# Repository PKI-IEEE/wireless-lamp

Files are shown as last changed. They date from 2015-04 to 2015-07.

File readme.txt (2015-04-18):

This is an LPCXpresso project for the LPC1343 that is being used on an RGBW Lamp for a PKI IEEE project Spring 2015. The lamp also uses an ESP8266 Wifi module.

Function Descriptions:

void setRed(uint8_t setValue);
Sets the red LED. Takes uint8_t value from 0 to 255 which controls the
brightness of the LED.
Example use:
	setRed(128) // sets red led to medium brightness

void setGreen(uint8_t setValue);
Sets the green LED. Takes uint8_t value from 0 to 255 which controls the
brightness of the LED.
Example use:
	setGreen(128) // sets green led to medium brightness

void setBlue(uint8_t setValue);
Sets the blue LED. Takes uint8_t value from 0 to 255 which controls the
brightness of the LED.
Example use:
	setBlue(128) // sets blue led to medium brightness

void setWhite(uint8_t setValue);
Sets the white LED. Takes uint8_t value from 0 to 255 which controls the
brightness of the LED.
Example use:
	setWhite(128) // sets white led to medium brightness

void setColor(uint8_t red, uint8_t green, uint8_t blue, uint8_t white);
Sets all 4 LEDs at once. Can be used to blend the LED colors.
Takes four uint8_t value from 0 to 255 which control the
brightness of the LEDs.
Example use:
	setColor(255, 255, 0, 0); // sets lamp to produce yellow color at full brightness

void testRed();
Brings the red led from off to full brightness in about 13 seconds.
	Example use:
		testRed();

void testGreen();
Brings the green led from off to full brightness in about 13 seconds.
	Example use:
		testGreen();

void testBlue();
Brings the blue led from off to full brightness in about 13 seconds.
	Example use:
		testBlue();

void testWhite();
Brings the white led from off to full brightness in about 13 seconds.
	Example use:
		testWhite();

void delay_us(uint32_t delay);
Uses TMR16B0 to create a delay in us.
	Example use:
		delay_us(1000); // delays for 1000 us

void delay_ms(uint32_t delay);
Uses delay_us function in a loop to create delay in ms
	Example use:
		delay_ms(1000); // delays for 1 second

void colorWheel(uint32_t delay);
Function written by Austin Steiner. Cycles gradually through the colors much like a color wheel.
Takes a uint32_t value that specifies the delay between changing colors in ms (100 is a good starting value)
Each call the the function cycles through the colors once. Best used in a loop.
	Example use:
		colorWheel(100);

void wifiConnect();
Sends UART command to EPS8266 running nodeMCU firmware to connect to a WiFi network.
Before calling this function ensure that you update the staConfig string in the function
to include your SSID and password.
	Example use:
		wifiConnect(); // causes ESP8266 to connect to Wifi network in station mode

struct ipStc getIp();
Returns a structure containing the four integer parts of the ESP8266s current IP address

void blinkIp(struct ipStc ipAddress);
This function takes an ipStc structure containing the current ESP8266s IP address and then
blinks the LEDs in a manner that will let the user know this IP address:

Blink Red = 100
Blink Blue = 10
Blink Green = 1
Blink white = dot (.)
Blink purple = end of IP

Example blink pattern:

Blue - White - Green Green Green - White - Red Blue Green Green - White - Blue Blue Green - Purple

This IP would be : 10.3.(100+10+2).(10+10+1) = 10.3.112.21

Example Use:
	blinkIp(getIp()); // blinks the LEDs to show the IP address using structure returned by getIp() function

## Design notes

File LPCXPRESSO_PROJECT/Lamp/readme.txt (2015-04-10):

This project contains the code for the RGBW LED Lamp. IEEE Spring 2015

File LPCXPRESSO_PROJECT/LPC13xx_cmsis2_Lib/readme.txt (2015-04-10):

LPC13xx_cmsis2_Lib
==================

This library project contains code to handle various peripherals contained
in the LPC13xx.

Several files have been modified slightly from the original NXP sources to
comment out application specific code (mainly the interrupt handlers).

This means that the library project only contains the common code. Interrupt
handlers are moved into projects making use of the peripherals.

The project makes use of code from the following library project:
- CMSISv2p00_LPC13xx : for CMSIS 2.00 files relevant to LPC13xx

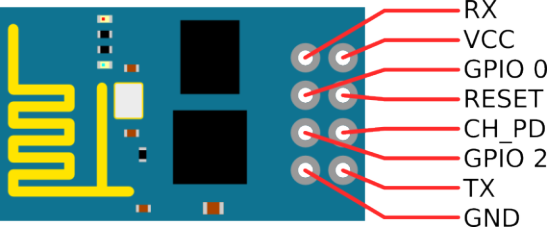
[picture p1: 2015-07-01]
BUILD_RELATED/esp8266_pinout.png

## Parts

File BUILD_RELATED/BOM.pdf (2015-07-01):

Component | Part Number | Quantity
Microcontroller | 568-4945-ND | 1
100k resistor | P100KFCT-ND | 5
150 resistor | P150ECT-ND | 2
1.5k resistor | P1.50KFCT-ND | 1
20k resistor | P20.0KFCT-ND | 1
10k resistor | P10.0KFCT-ND | 2
2k resistor | P2.00KFCT-ND | 1
1k resistor | P1.00KFCT-ND | 1
33 resistor | P33.0FCT-ND | 2
15 1W resistor | 15DLCT-ND | 2
10 1W resistor | 10WCT-ND | 6
10uF capacitor | 1276-1075-1-ND | 5
0.1uf capacitor | 1276-1017-1-ND | 5
16pF capacitor | 1276-2809-1-ND | 2
220uF capacitor | 493-5904-1-ND | 4
12MHz crystal | 644-1047-1-ND | 1
Tact Switch | P12940SCT-ND | 2
USB Mini B | ED2992CT-ND | 1
LED (USB, PWR Indicator) | 754-1141-1-ND | 2
Schottiky Diode Array | 497-3786-1-ND | 1
3.3V Regulator | LM1117IMPX-3.3/NOPBCT-ND | 1
PNP Transistor | MMBT2907A-TPMSCT-ND | 1
IC Supervisor 3.15V | MCP130T-315I/TTCT-ND | 1
PCB | | 1
N-Channel MOSFET | FQP50N06L-ND | 4
1W Power LED | 4W RGBW | 2
Wifi Module | ESP8266 | 1
Female Headers 4 pin | | 2
Female Headers 40 pin | | 1
Barrel Jack | EJ508A-ND | 1
DC Supply | 2.5A | 1

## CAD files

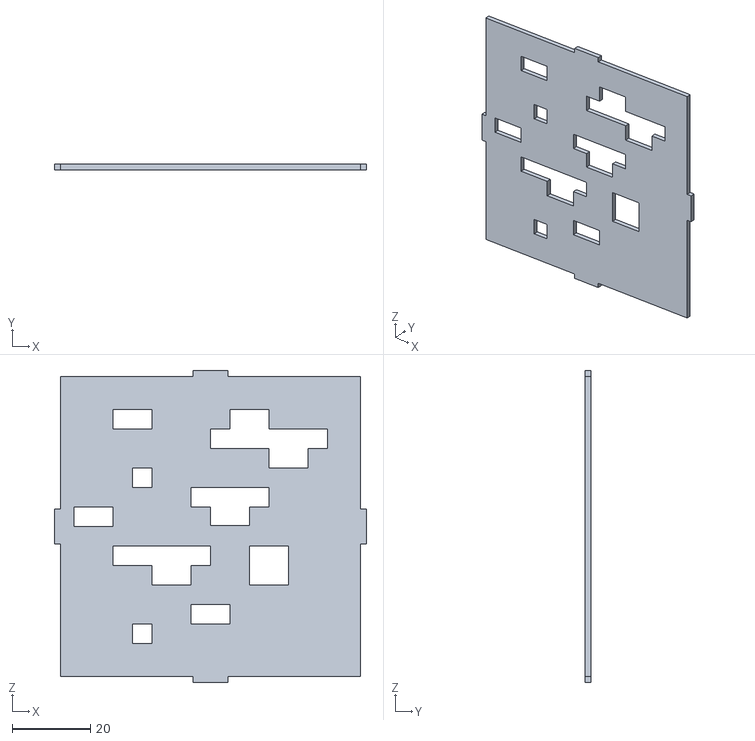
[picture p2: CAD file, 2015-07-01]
BUILD_RELATED/STLs/minecraft_wall_2.stl
80.0 x 1.50 x 80.0

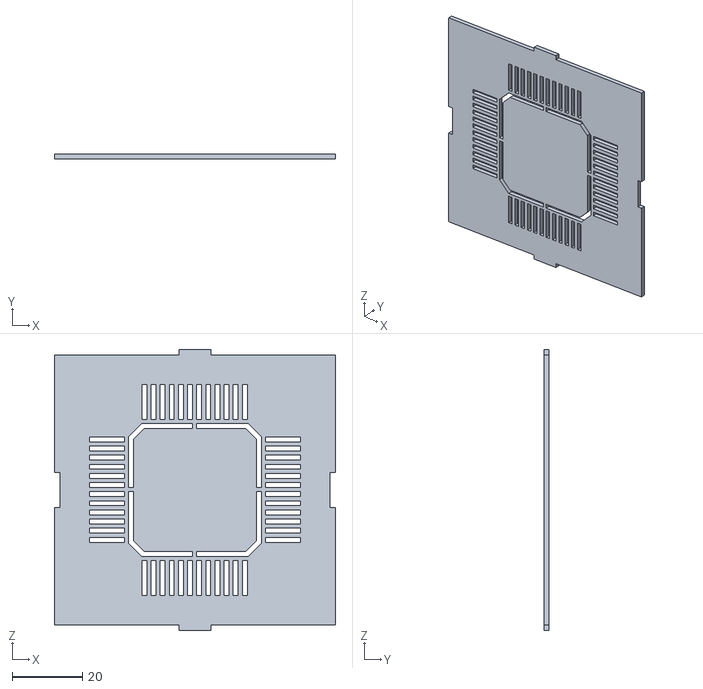
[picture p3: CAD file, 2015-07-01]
BUILD_RELATED/STLs/circuit_wall_2.stl
80.0 x 1.50 x 80.0

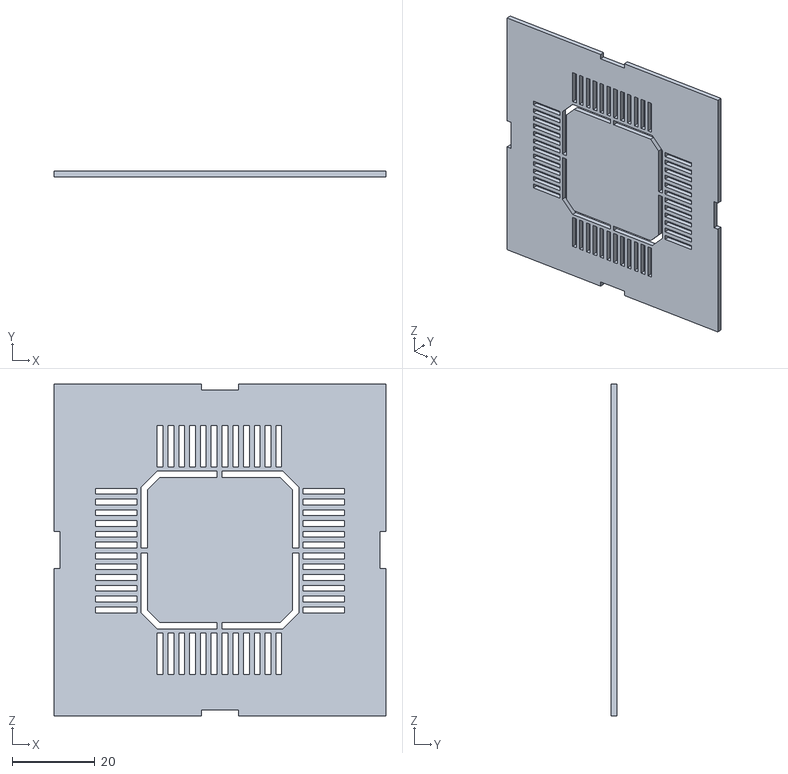
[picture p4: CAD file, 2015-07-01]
BUILD_RELATED/STLs/circuit_top.stl
80.0 x 1.50 x 80.0

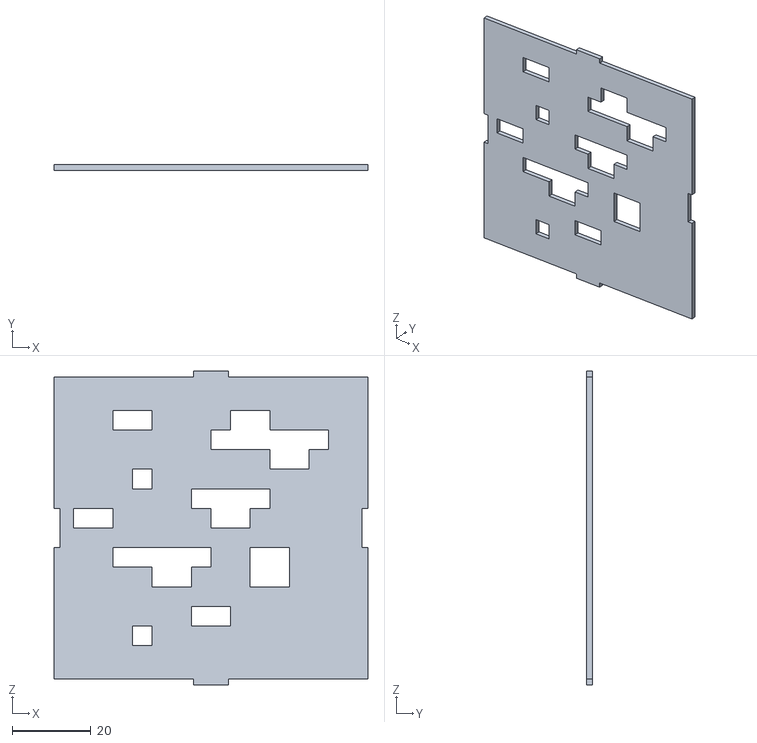
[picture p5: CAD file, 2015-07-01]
BUILD_RELATED/STLs/minecraft_wall_1.stl
80.0 x 1.50 x 80.0

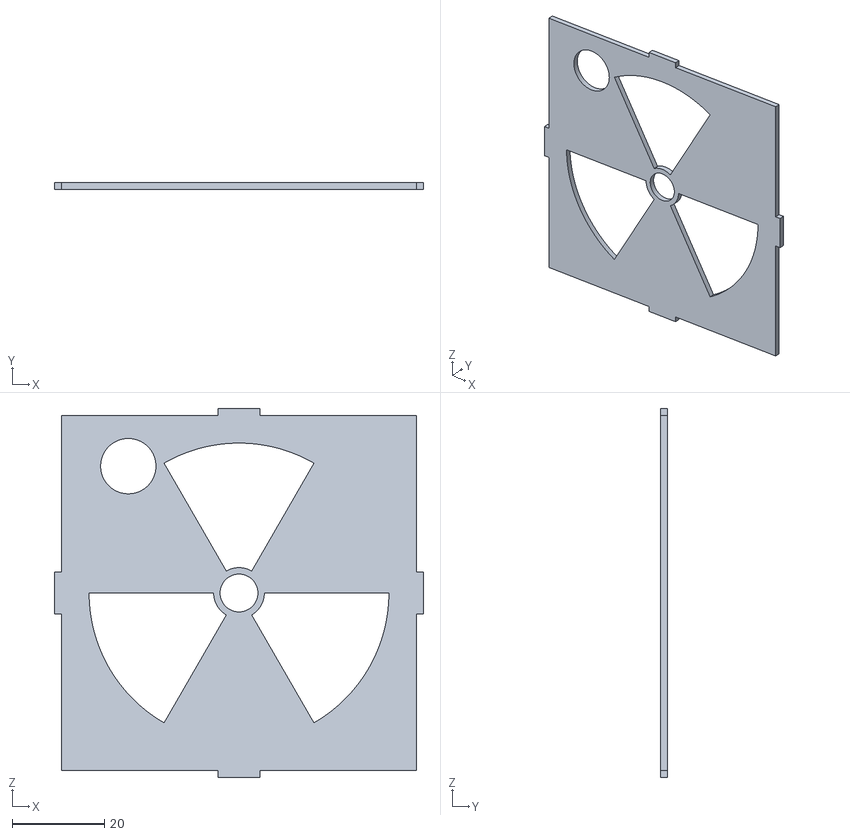
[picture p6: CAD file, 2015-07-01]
BUILD_RELATED/STLs/hazard_wall_3.stl
80.0 x 1.50 x 80.0

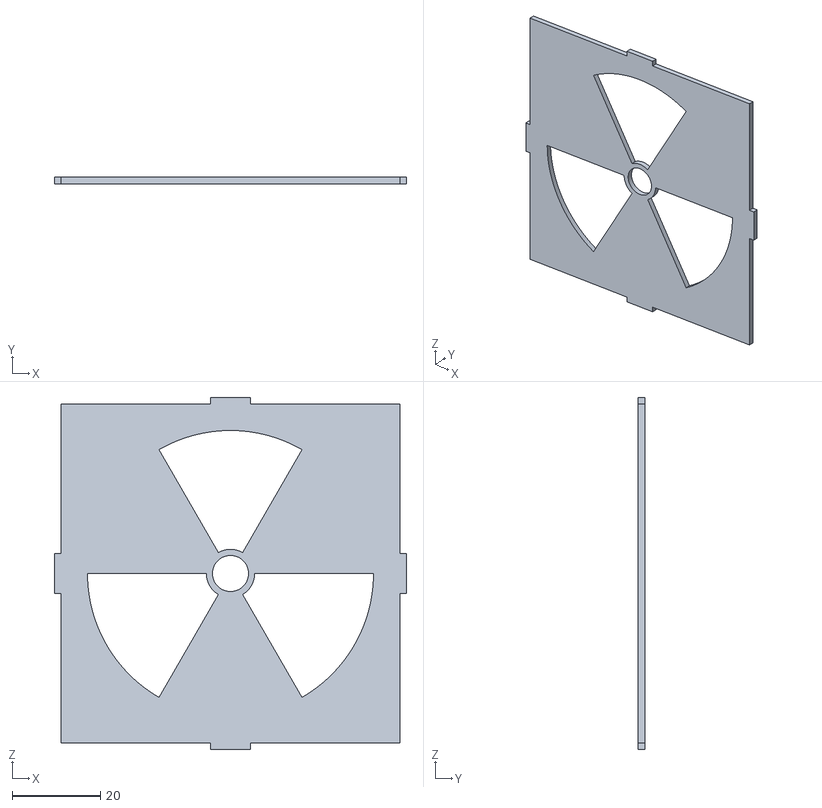
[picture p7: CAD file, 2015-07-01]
BUILD_RELATED/STLs/hazard_wall_1.stl
80.0 x 1.50 x 80.0

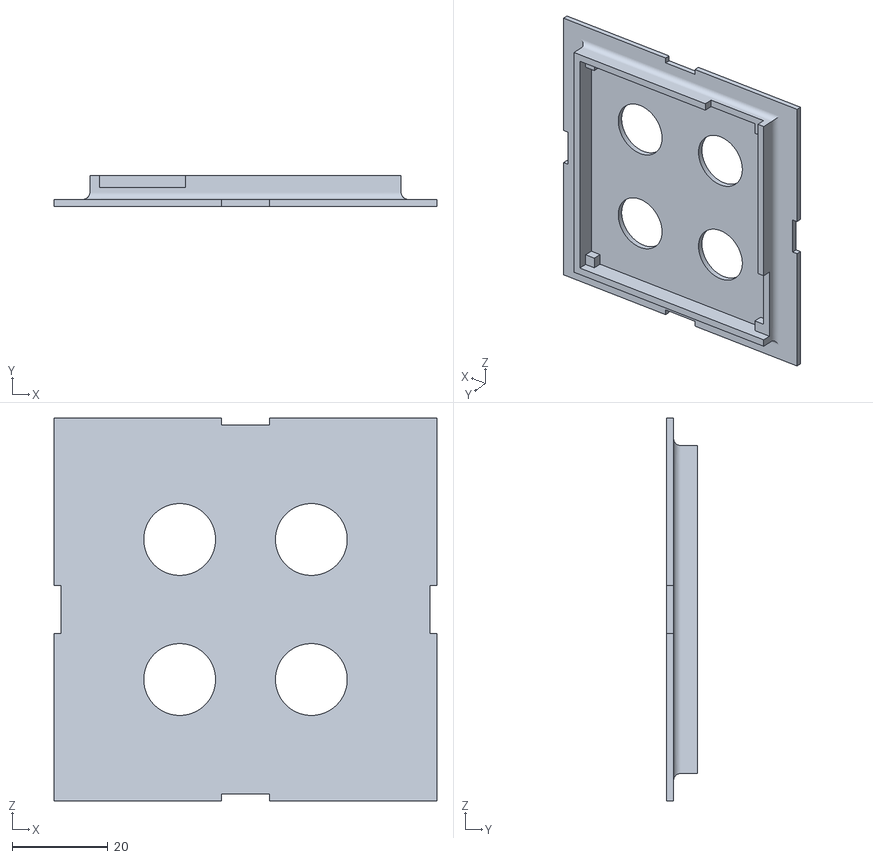
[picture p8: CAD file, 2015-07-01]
BUILD_RELATED/STLs/lamp_bottom.stl
80.0 x 6.50 x 80.0

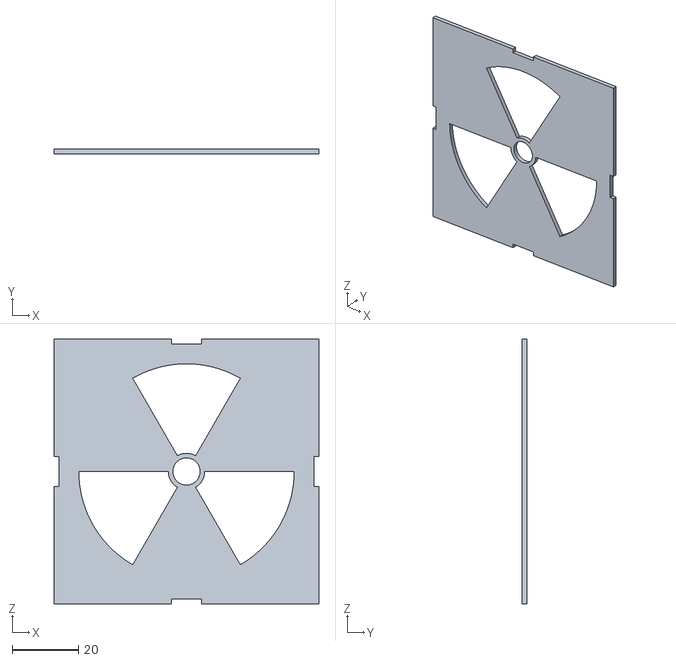
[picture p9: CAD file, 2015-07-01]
BUILD_RELATED/STLs/hazard_top.stl
80.0 x 1.50 x 80.0

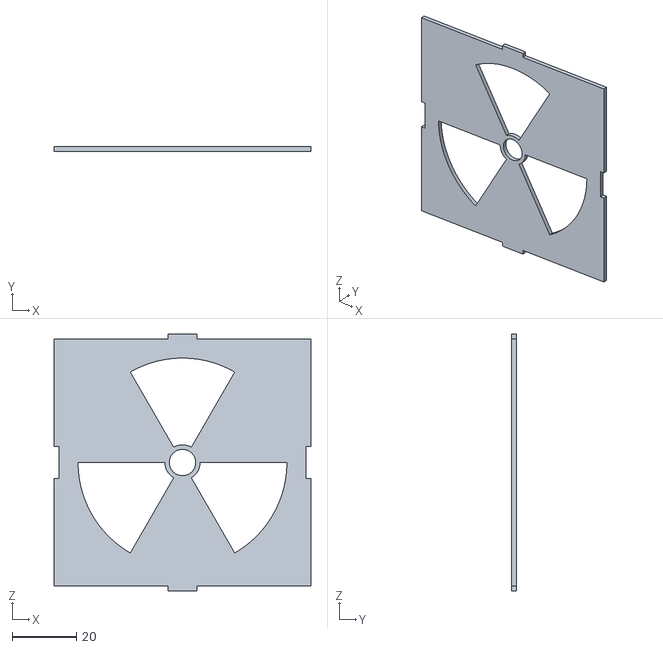
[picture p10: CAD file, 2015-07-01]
BUILD_RELATED/STLs/hazard_wall_2.stl
80.0 x 1.50 x 80.0

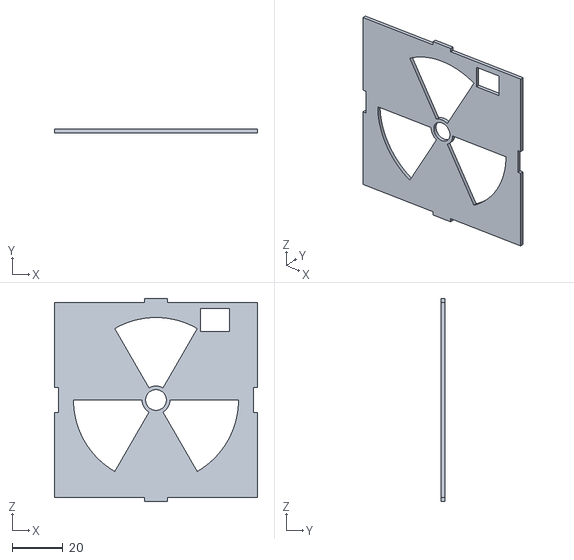
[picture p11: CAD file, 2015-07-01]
BUILD_RELATED/STLs/hazard_wall_4.stl
80.0 x 1.50 x 80.0

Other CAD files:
BUILD_RELATED/STLs/circuit_wall_1.stl
BUILD_RELATED/STLs/minecraft_wall_4.stl
BUILD_RELATED/STLs/circuit_wall_3.stl
BUILD_RELATED/STLs/minecraft_top.stl
BUILD_RELATED/STLs/minecraft_wall_3.stl
BUILD_RELATED/STLs/circuit_wall_4.stl

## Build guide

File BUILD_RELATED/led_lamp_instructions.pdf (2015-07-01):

# LED Wi-Fi Lamp Build Instructions

# PKI IEEE April 2015

Component | Quantity
Microcontroller | 1
100k Ω resistor | 5
150 Ω resistor | 2
1.5k Ω resistor | 1
20k Ω resistor | 1
10k Ω resistor | 2
2k Ω resistor | 1
1k Ω resistor | 1
33 Ω resistor | 2
15 Ω 1W resistor | 2
10 Ω 1W resistor | 6
10uF capacitor | 5
0.1uf capacitor | 5
16pF capacitor | 2
220uF capacitor | 4
12MHz crystal | 1
Tact Switch | 2
USB Mini B | 1
LED (USB, PWR Indicator) | 2
Schottky Diode Array | 1
3.3V Regulator | 1
PNP Transistor | 1
IC Supervisor 3.15V | 1
PCB | 1
N -Channel MOSFET | 4
1W RGBW LED | 2
ESP8266 Wi -Fi Module | 1
Female Headers 4 pin | 2
Female Headers 40 pin | 1
Barrel Jack | 1
DC Supply | 1

This project will be more involved and will require a greater attention to detail than some of the previous projects. Please take your time when assembling this project. If you have any questions, if anything is unclear, or if you need assistance, please ask.

When soldering surface mount devices (SMD) only remove one component from the tape at a time. These parts are small and can be easily lost. There are not many extra parts so if you do loose one you will have to search for it.

There is not a special order the components of this PCB should be soldered in. It is
recommended that you choose one component and solder all of those components at one time. For instance, there are five 10µF capacitors. All five should be soldered before moving on. This will reduce the likelihood of loosing a component.

You may want to look through all of the pages of these instructions before you begin.

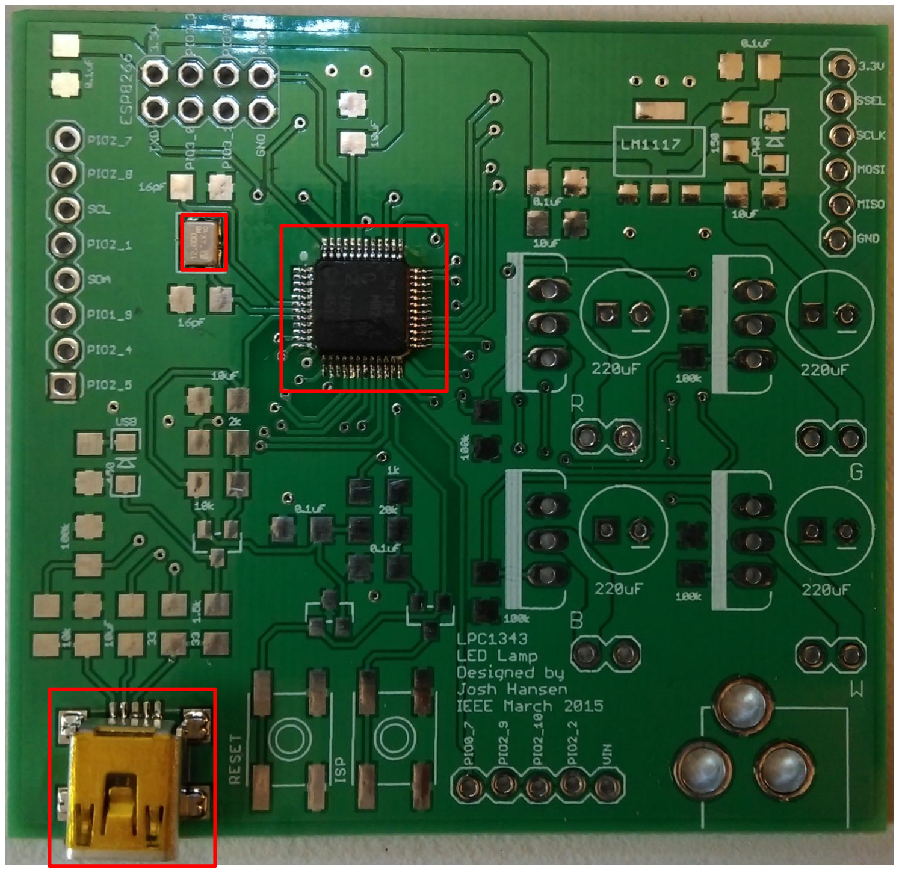
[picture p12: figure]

Components in red
should be pre-soldered
when you receive your
board. If one of these
three components is
missing let an officer
know.

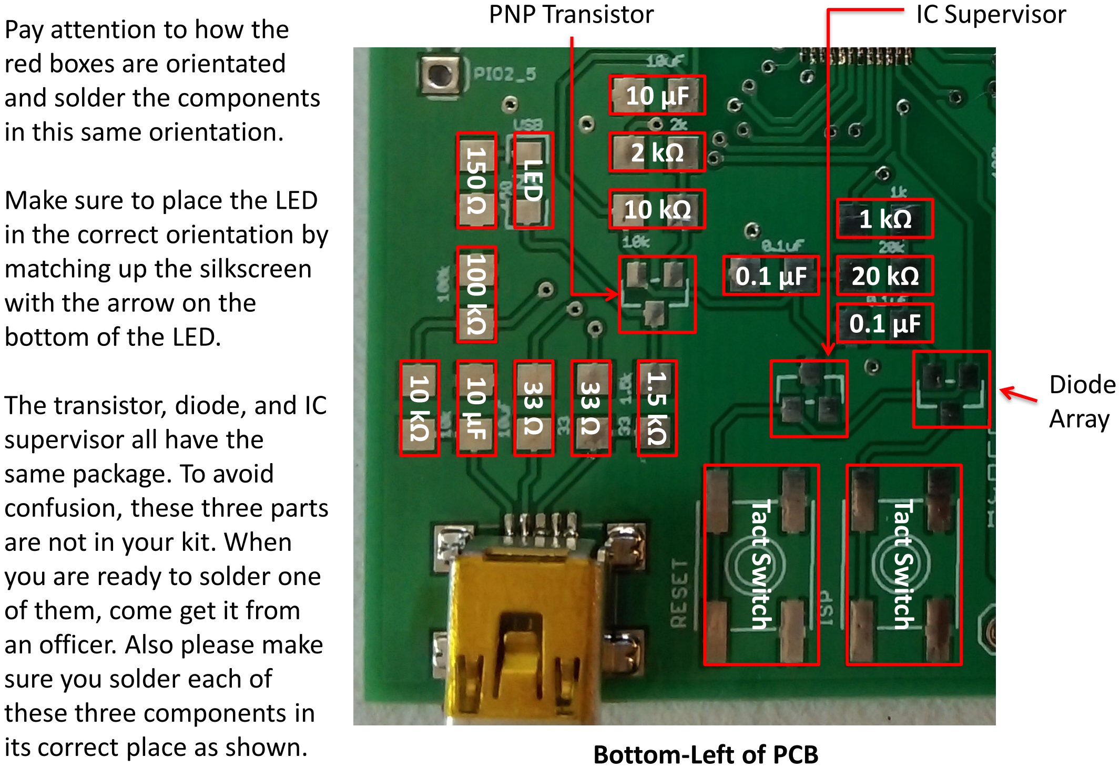
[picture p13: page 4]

### 10 k

Ω

### 10 µF

33

Ω

33

Ω

### 1.5 k

Ω

100 k

Ω 150

Ω

LED

### 10 µF

### 2 kΩ

### 10 kΩ

### 0.1 µF

### 1 kΩ

### 20 kΩ

### 0.1 µF

Tact Switch

Tact Switch

PNP Transistor | IC Supervisor

Diode
Array

Bottom-Left of PCB

Pay attention to how the
red boxes are orientated
and solder the components
in this same orientation.

Make sure to place the LED in the correct orientation by matching up the silkscreen with the arrow on the
bottom of the LED.

The transistor, diode, and IC supervisor all have the
same package. To avoid
confusion, these three parts are not in your kit. When
you are ready to solder one of them, come get it from
an officer. Also please make sure you solder each of
these three components in
its correct place as shown.

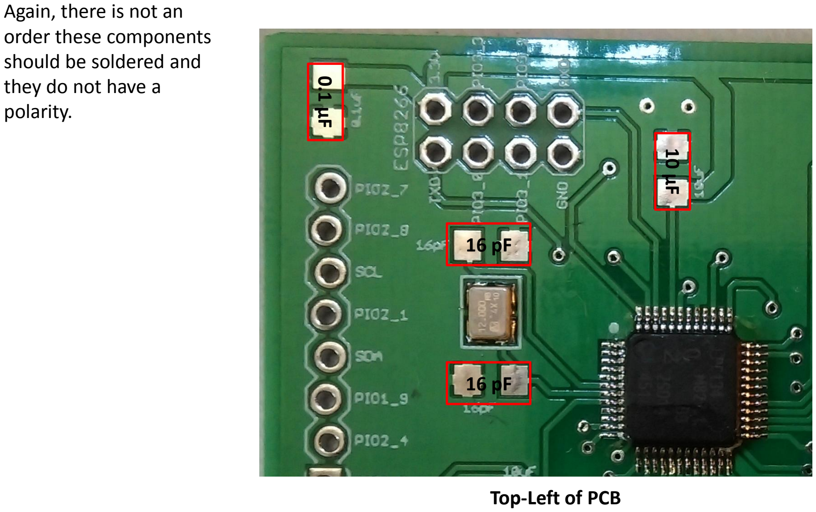
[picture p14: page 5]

### 10 µF

### 16 pF

### 16 pF

### 0.1 µF

Top-Left of PCB

Again, there is not an
order these components
should be soldered and
they do not have a
polarity.

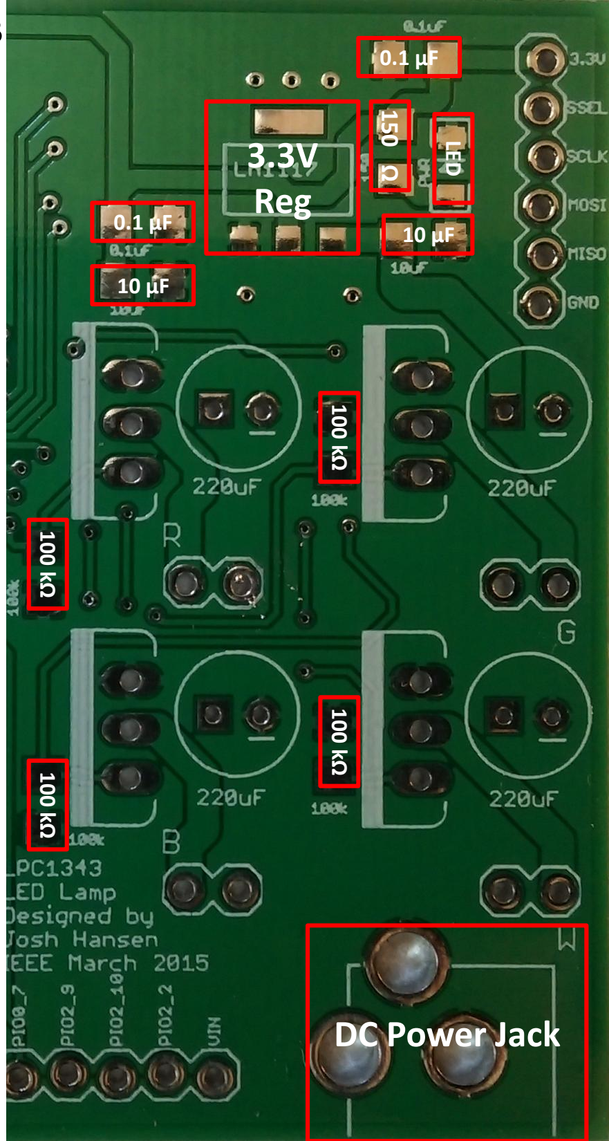
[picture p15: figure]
LED; DC Power Jack; 3.3V Reg

Right Half of PCB

Solder all surface mount components shown in red first. Again, pay attention to how the red boxes are orientated. It is possible to solder components across the wrong pads if you don’t pay attention.

Make sure to place the LED in the correct orientation by matching up the silkscreen with the arrow on the bottom of the LED.

Once you have all the SMD components soldered, ask an officer to check your board if you want. Once you solder in the capacitors and mosfets it will be difficult to make changes to some of the SMD parts.

Once you are comfortable with your SMD parts, solder the mosfets, large capacitors, DC power jack, and headers. Use the completed image on the next page as a reference and pay attention to the polarity of the capacitors and the orientation of the mosfets.

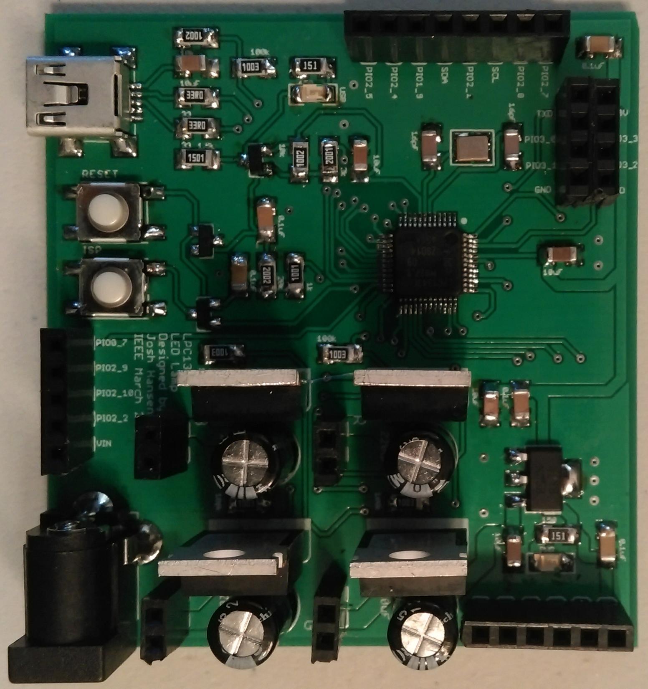
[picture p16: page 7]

Completed board for
reference.

This is the circuit for the LEDs that you will need to create using the resistors and wire provided. Notice that the red LEDs use 15 Ω resistors while the other three use 10 Ω. Also notice that every LED has a resistor in series. You should have no extra resistors when you are done.

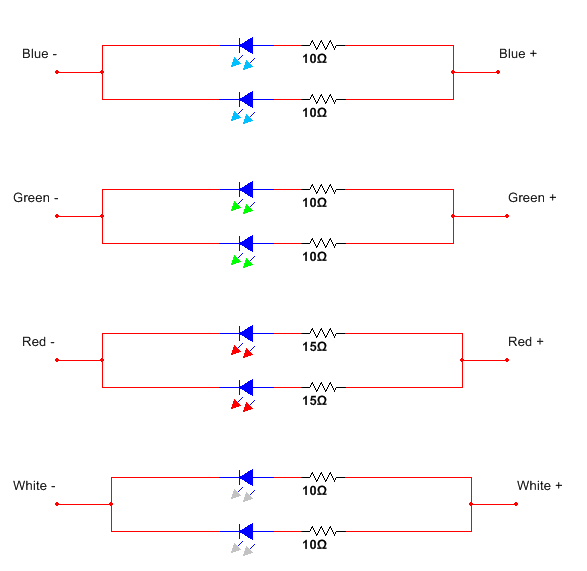
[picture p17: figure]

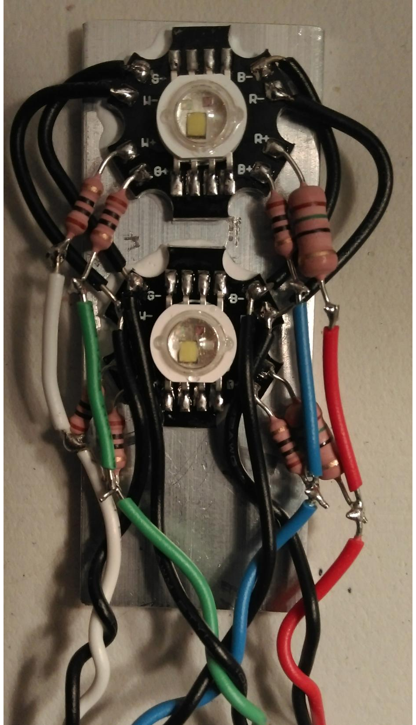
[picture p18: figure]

This is an example of how the circuit from the previous page was implemented. This is only one way of doing it, it doesn’t have to be done this way. Pay attention to the silk screen markings for the LEDs. The G for green and the B for blue can look the same. If you can’t tell which is which, ask.

Keep the amount of wire used to a minimum. If you are using one of the cube cases you will want just enough wire to go from the LEDs to the PCB. If using the lamp structure you will need more wire to go from the LEDs to the PCB.

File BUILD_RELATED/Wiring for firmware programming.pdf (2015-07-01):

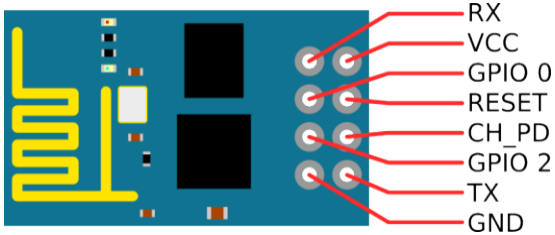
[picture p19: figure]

Wiring for firmware programming:

- RX -> TX
- TX -> RX
- CH_PD -> 3.3V
- GPIO 0 -> GND
- VCC -> 3.3V
- GND -> GND

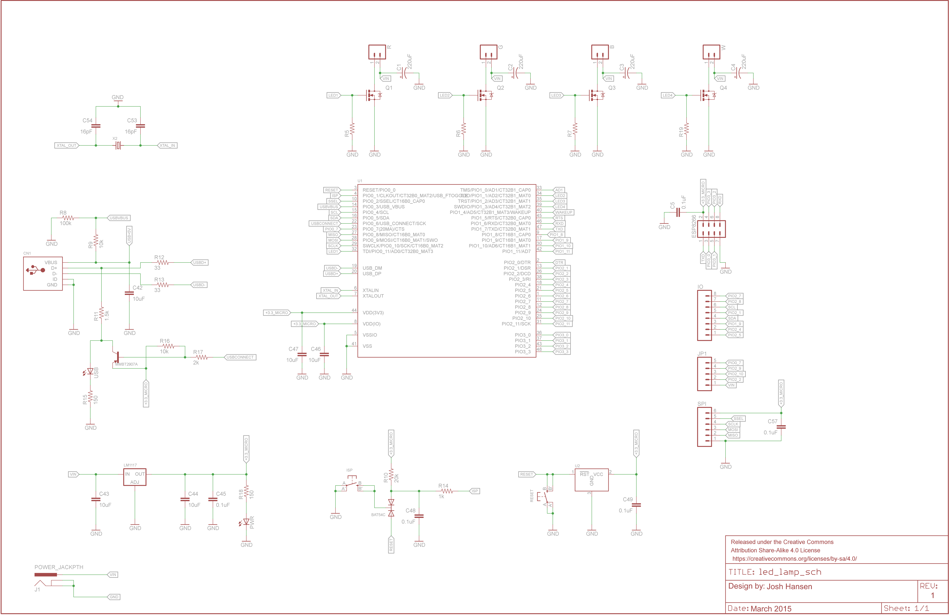
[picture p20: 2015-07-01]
BUILD_RELATED/led_lamp_sch.png

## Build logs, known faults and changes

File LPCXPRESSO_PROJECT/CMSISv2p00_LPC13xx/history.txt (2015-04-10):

History of updates to CMSISv2p00_LPC13xx
========================================

28 April 2011
-------------
Updated with new LPC13xx.h (dated 2011-04-28). Some registers
have been renamed, though originals have been left in place
via the use of unions. It is recommended that code is ported
to use the new names...

In LPC_SYSCON_TypeDef...
... SSPCLKDIV => SSP0CLKDIV

In LPC_IOCON_TypeDef...
... JTAG_TCK_PIO0_10 => SWCLK_PIO0_10
... JTAG_TDI_PIO0_11 => R_PIO0_11
... JTAG_TMS_PIO1_0 => R_PIO1_0
... JTAG_TDO_PIO1_1 => R_PIO1_1
... JTAG_nTRST_PIO1_2 => R_PIO1_2
... ARM_SWDIO_PIO1_3 => SWDIO_PIO1_3 
... SCK_LOC => SCKLOC 

In LPC_ADC_TypeDef...
... DR0,DR1...DR7 => DR[8] 

In IRQn_Type...
... SSP_IRQn => SSP0_IRQn

In APB0 peripherals #define's...
... LPC_SSP_BASE => LPC_SSP0_BASE

Other minor changes to LPC13xx.h due to changes in LPC1300L
parts. Also added power_api.h for use by LPC1300L parts.

7 March 2011
------------
LPC13xx CMSIS 2.0 library project using ARM 
Cortex-M3 CMSIS files as supplied in ARM's CMSIS 2.0
December 2010 release, together with device/board 
specific files from NXP (as previously supplied in
CMSISv1p30_LPC13xx library project, dated 23 Mar 2010).

Note files are built -Os for both Debug and Release

10 March 2014
-------------
NXP Minor change to core_cmInstr.h to add & to prefix result for byte and half word strex functions - for GCC compatibility.

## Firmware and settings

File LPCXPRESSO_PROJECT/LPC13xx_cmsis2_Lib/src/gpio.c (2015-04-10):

/*****************************************************************************
 *   gpio.c:  GPIO C file for NXP LPC13xx Family Microprocessors
 *
 *   Copyright(C) 2008, NXP Semiconductor
 *   All rights reserved.
 *
 *   History
 *   2009.12.09  ver 1.01    GPIOSetValue() updated
 *   2008.07.20  ver 1.00    Preliminary version, first Release
 *
*****************************************************************************/
#include "LPC13xx.h"			/* LPC13xx Peripheral Registers */
#include "gpio.h"

/* ===================
 * CodeRed - Modified file to extract out interrupt handler related code,
 * which is really application project specific.
 * Set GPIO_GENERIC_INTS 1 to 1 to reenable original code.
 * =================== */
//#define GPIO_GENERIC_INTS 1

#ifdef GPIO_GENERIC_INTS
volatile uint32_t gpio0_counter = 0;
volatile uint32_t gpio1_counter = 0;
volatile uint32_t gpio2_counter = 0;
volatile uint32_t gpio3_counter = 0;
volatile uint32_t p0_1_counter  = 0;
volatile uint32_t p1_1_counter  = 0;
volatile uint32_t p2_1_counter  = 0;
volatile uint32_t p3_1_counter  = 0;

/*****************************************************************************
** Function name:		PIOINT0_IRQHandler
**
** Descriptions:		Use one GPIO pin(port0 pin1) as interrupt source
**
** parameters:			None
** Returned value:		None
** 
*****************************************************************************/
void PIOINT0_IRQHandler(void)
{
  uint32_t regVal;

  gpio0_counter++;
  regVal = GPIOIntStatus( PORT0, 1 );
  if ( regVal )
  {
	p0_1_counter++;
	GPIOIntClear( PORT0, 1 );
  }		
  return;
}

/*****************************************************************************
** Function name:		PIOINT1_IRQHandler
**
** Descriptions:		Use one GPIO pin(port1 pin1) as interrupt source
**
** parameters:			None
** Returned value:		None
** 
*****************************************************************************/
void PIOINT1_IRQHandler(void)
{
  uint32_t regVal;

  gpio1_counter++;
  regVal = GPIOIntStatus( PORT1, 1 );
  if ( regVal )
  {
	p1_1_counter++;
	GPIOIntClear( PORT1, 1 );
  }		
  return;
}

/*****************************************************************************
** Function name:		PIOINT2_IRQHandler
**
** Descriptions:		Use one GPIO pin(port2 pin1) as interrupt source
**
** parameters:			None
** Returned value:		None
** 
*****************************************************************************/
void PIOINT2_IRQHandler(void)
{
  uint32_t regVal;

  gpio2_counter++;
  regVal = GPIOIntStatus( PORT2, 1 );
  if ( regVal )
  {
	p2_1_counter++;
	GPIOIntClear( PORT2, 1 );
  }		
  return;
}

/*****************************************************************************
** Function name:		PIOINT3_IRQHandler
**
** Descriptions:		Use one GPIO pin(port3 pin1) as interrupt source
**
** parameters:			None
** Returned value:		None
** 
*****************************************************************************/
void PIOINT3_IRQHandler(void)
{
  uint32_t regVal;

  gpio3_counter++;
  regVal = GPIOIntStatus( PORT3, 1 );
  if ( regVal )
  {
	p3_1_counter++;
	GPIOIntClear( PORT3, 1 );
  }		
  return;
}
#endif //GPIO_GENERIC_INTS

/*****************************************************************************
** Function name:		GPIOInit
**
** Descriptions:		Initialize GPIO, install the
**						GPIO interrupt handler
**
** parameters:			None
** Returned value:		true or false, return false if the VIC table
**						is full and GPIO interrupt handler can be
**						installed.
** 
*****************************************************************************/
void GPIOInit( void )
{
  /* Enable AHB clock to the GPIO domain. */
  LPC_SYSCON->SYSAHBCLKCTRL |= (1<<6);

#ifdef __JTAG_DISABLED  
  LPC_IOCON->JTAG_TDO_PIO1_1  &= ~0x07;
  LPC_IOCON->JTAG_TDO_PIO1_1  |= 0x01;
#endif

  /* Set up NVIC when I/O pins are configured as external interrupts. */
  NVIC_EnableIRQ(EINT0_IRQn);
  NVIC_EnableIRQ(EINT1_IRQn);
  NVIC_EnableIRQ(EINT2_IRQn);
  NVIC_EnableIRQ(EINT3_IRQn);
  return;
}
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

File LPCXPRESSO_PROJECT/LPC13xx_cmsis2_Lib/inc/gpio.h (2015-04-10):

/*****************************************************************************
 *   gpio.h:  Header file for NXP LPC13xx Family Microprocessors
 *
 *   Copyright(C) 2008, NXP Semiconductor
 *   All rights reserved.
 *
 *   History
 *   2008.09.01  ver 1.00    Preliminary version, first Release
 *
******************************************************************************/
#ifndef __GPIO_H 
#define __GPIO_H

#define PORT0		0
#define PORT1		1
#define PORT2		2
#define PORT3		3

void GPIO_IRQHandler(void);
void GPIOInit( void );
void GPIOSetDir( uint32_t portNum, uint32_t bitPosi, uint32_t dir );
void GPIOSetValue( uint32_t portNum, uint32_t bitPosi, uint32_t bitVal );
void GPIOSetInterrupt( uint32_t portNum, uint32_t bitPosi, uint32_t sense,
		uint32_t single, uint32_t event );
void GPIOIntEnable( uint32_t portNum, uint32_t bitPosi );
void GPIOIntDisable( uint32_t portNum, uint32_t bitPosi );
uint32_t GPIOIntStatus( uint32_t portNum, uint32_t bitPosi );
void GPIOIntClear( uint32_t portNum, uint32_t bitPosi );

#endif /* end __GPIO_H */
/*****************************************************************************
**                            End Of File
******************************************************************************/

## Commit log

2015-04-14 Fixed colorWheel function to not skip colors.
    [led.c]
2015-04-16 Color set functions now use the gamma table to set the LED color.
2015-04-18 Added functions to retrieve IP address and blink it out with the LEDs.
2015-07-01 Added build materials
    [circuit_top.stl, circuit_wall_1.stl, circuit_wall_2.stl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]
